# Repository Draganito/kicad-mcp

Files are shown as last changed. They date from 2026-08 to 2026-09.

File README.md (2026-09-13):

# kicad-mcp

I built this because I needed a replacement LED panel for my
**Beseler 4×5** enlarger (MILUKA Aristo D2). I had never designed a
PCB, and I did not want to learn KiCad by clicking through menus.

So you keep **KiCad** open. In **Cursor** you tell an assistant what
the board should be — in plain language. It downloads the real JLCPCB
parts, places them, assigns the nets, pours the copper, checks its own
work, and writes the files JLCPCB actually accepts.

This is not a second PCB editor and not “chat, invent a `.kicad_pcb`”.
KiCad stays the source of truth. Every change is **Ctrl+Z**. Nothing
is saved unless you ask.

**Proof it works:** the board that started it —
[contrib/aristo-d2-led-panel](contrib/aristo-d2-led-panel), 109 SK6812
LEDs, 4 layers, designed this way from the first outline to the
ordered Gerbers, manufactured by JLCPCB.

**Work in progress:**
[contrib/aristo-d2-led-panel-v2](contrib/aristo-d2-led-panel-v2) —
112× WS2812B-MINI drop-in. Layout and gerbers only; not a build guide.

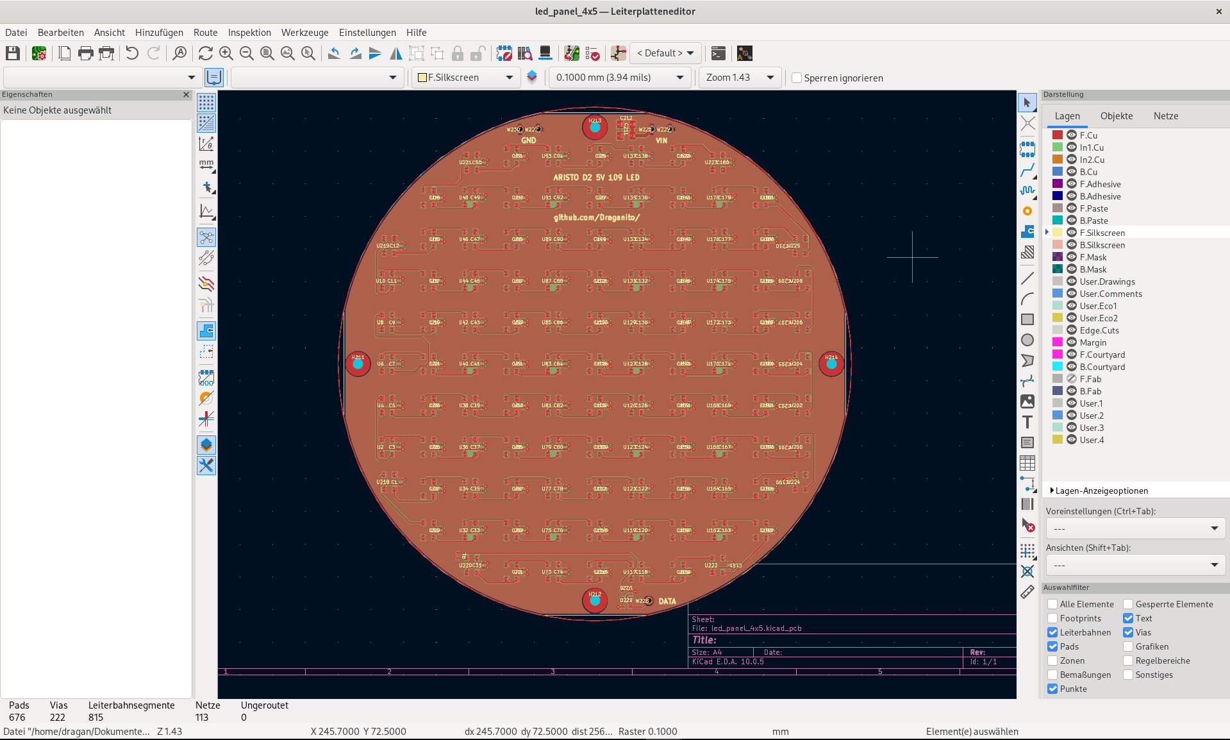
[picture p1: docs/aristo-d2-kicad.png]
MILUKA Aristo D2 replacement LED panel in KiCad


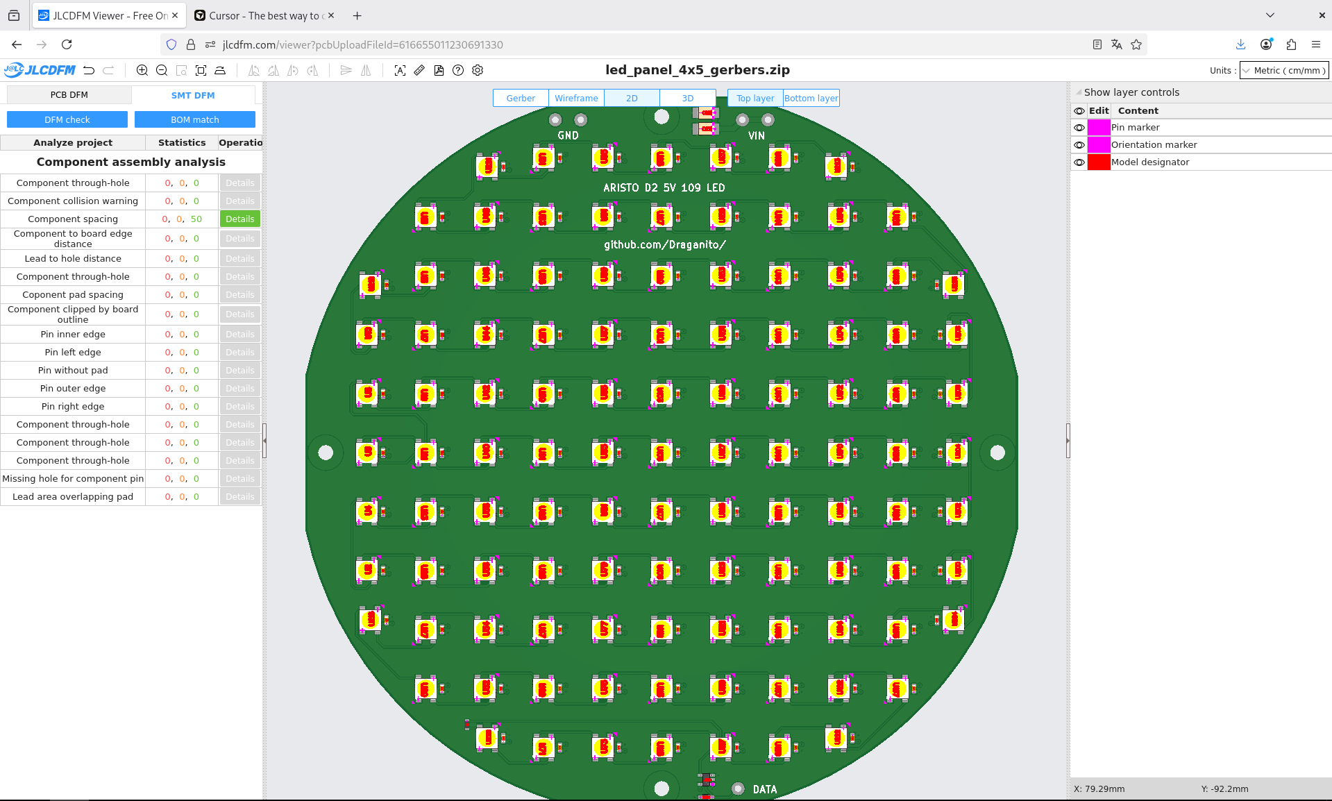
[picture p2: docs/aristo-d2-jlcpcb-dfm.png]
MILUKA Aristo D2 replacement LED panel in JLCPCB DFM


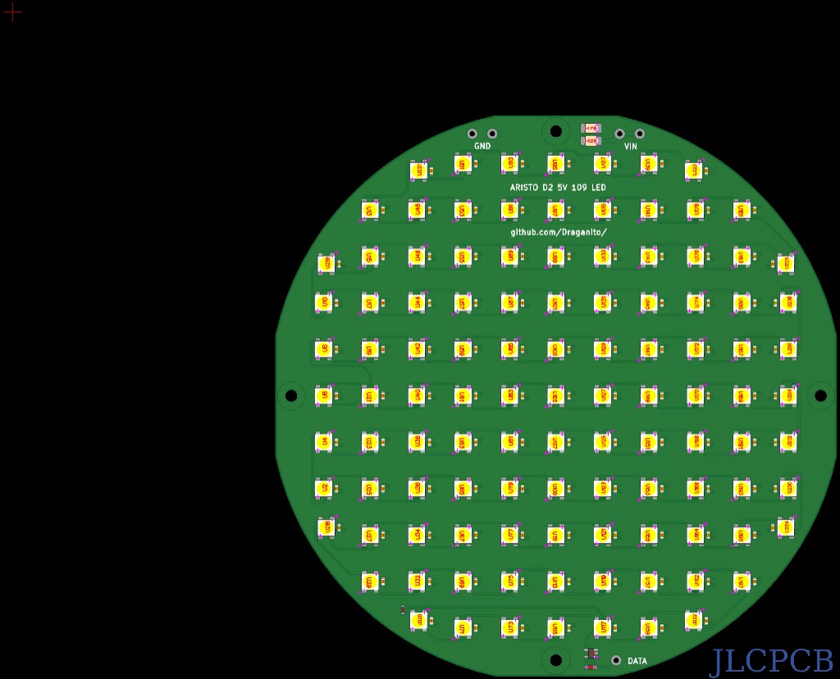
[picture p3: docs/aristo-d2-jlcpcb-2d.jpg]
MILUKA Aristo D2 replacement LED panel, JLCPCB 2D view


**Docs:** [Install on Debian](docs/INSTALL_DEBIAN.md) ·
[Manual (A–Z reference)](docs/MANUAL.md)

---

## Who this is for

Students, hobbyists, makers on **Debian/Ubuntu** who want help with
the boring bits: a LED grid, wire pads, a GND pour, Gerbers that
JLCPCB accepts — without learning a pro tool first.

You still decide the circuit. The assistant must not invent pin
functions — those come from the LCSC / EasyEDA part, and built-in
checks (`check_pins`, `check_placement`, `review_board`) force it to
account for every pin instead of hand-waving.

Skip this if you layout in Altium, only have Windows, or do not want
an assistant in the editor at all.

---

## What you need

- A PC with Debian or Ubuntu (x86-64)
- [KiCad 10](https://www.kicad.org/download/linux/) — not Debian’s
  KiCad 9
- [Cursor](https://cursor.com)
- An LCSC part number when you want a real JLCPCB footprint
  (e.g. `C14663` for an 0603 cap)

---

## Install

1. Download the latest `kicad-mcp_*.deb` from
   **[Releases](https://github.com/Draganito/kicad-mcp/releases)**.
2. Install it:

   ```bash
   sudo apt install ./kicad-mcp_*_amd64.deb
   ```

3. Start KiCad with **`kicad-10`** (comes with the package). Open the
   PCB editor. Enable **Preferences → Plugins → Enable IPC API**, then
   restart KiCad and open the PCB editor again.
4. Copy the Cursor template into the folder you will open:

   ```bash
   cp -a /usr/share/kicad-mcp/cursor-setup/.cursor \
         /usr/share/kicad-mcp/cursor-setup/.cursorignore .
   ```

5. In Cursor, toggle the `kicad-mcp` server off and on.

The autorouter (`kicad-routing-tools_*.deb`, same Releases page) is
**optional**. If you want it: install it too, then run
`kicad-routing-tools-setup` once as your user.

Full walkthrough from a clean machine (AppImage, both packages):
[docs/INSTALL_DEBIAN.md](docs/INSTALL_DEBIAN.md).

---

## First thing to ask

KiCad 10 running, a board open, Cursor on that folder:

> Call `board_summary`.

You want KiCad **10.x**, `has_open_board: true`, and
`net_ipc_persists: true`. If it says 9.x, you started the wrong KiCad
— use `kicad-10`.

Then, in plain language, for example:

> Make a 40 × 30 mm board. Download C14663. Place one cap in the
> middle. Don’t save yet.

Undo is always **Ctrl+Z** in KiCad. The assistant must not save
unless you ask.

---

## How a board usually gets built

1. **Outline** — the yellow Edge.Cuts rectangle *is* the PCB. The pink
   A4 frame is only the drawing sheet.
2. **Parts** — LCSC C-numbers (`download_lcsc_part`), then place or
   a grid (`place_matrix`). Pin names come from EasyEDA, not from
   memory.
3. **Nets** — ratsnest only (`connect_many`). Copper comes later.
4. **Check the nets** — `check_pins`: every pin must be netted or
   explicitly allowed open. No silent floating pins.
5. **Copper** — tracks, vias, 4-layer stack if you need it, GND/5V
   pours. Or named-net autoroute (not GND).
6. **Silk** — `5V` / `GND` / `DATA` next to wire pads. Not on copper.
7. **Check the board** — clearance (`check_drc`), connectivity
   (`check_board`), layout physics (`review_board`).
8. **Order** — `export_manufacturing` writes the JLCPCB zip + BOM +
   pick-and-place. Silk has no U1/C3 (JLCPCB DFM).

Coordinates are millimetres, **+x right, +y up**. Do not edit
`.kicad_pcb` by hand.

The assistant has a small tool list on purpose. The A–Z names live in
the [manual](docs/MANUAL.md).

---

## If something fails

| What you see | Usual cause |
| --- | --- |
| MCP cannot connect | PCB editor closed, or IPC API still off |
| Version 9 / nets empty | System KiCad instead of `kicad-10` |
| Writes refused | Cursor template not copied (needs `--allow-ai-write`) |
| Parts piled in the sheet corner | A bug in pad coordinates — not you; say so |
| AppImage runs, no socket | `.AppImage` started directly instead of `kicad-10` |

More: [manual](docs/MANUAL.md) → “Troubleshooting”.

---

## Build from source

Only if you are changing the Rust code. Makers can stop at the `.deb`.

```bash
cargo test --workspace
cargo build --release -p kicad-mcp
```

Debian package: `dist/make_beta_package.sh` (needs `cargo-deb`).
Point Cursor at the **built binary**, not `cargo run`. After a rebuild,
toggle the MCP server off/on.

Layout of the repo: [docs/architecture.md](docs/architecture.md).

---

## License

[AGPL-3.0-only](LICENSE) — Copyright © 2026 Dragan Bojovic.
See [NOTICE](NOTICE).

KiCad is a separate GPL-3.0 program. This repo only talks to it over
the published IPC API.

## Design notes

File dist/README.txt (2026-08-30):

kicad-mcp — Debian package
==========================

Prebuilt Linux build of kicad-mcp (AGPL-3.0) as a .deb package.
Lay out a PCB in a running KiCad PCB editor, from Cursor.
Footprints come from EasyEDA/LCSC so they match JLCPCB.
Start here: README.md (same doc folder).
Source: https://github.com/Draganito/kicad-mcp
License notices: LICENSE.txt

Install
-------
  sudo apt install ./kicad-mcp_<version>_amd64.deb

What is where
-------------
  /usr/bin/kicad-mcp                          MCP server (stdio, Linux x86-64)
  /usr/bin/kicad-10                           Wrapper: AppImage with TMPDIR=/tmp
  /usr/share/applications/kicad-10.desktop    Menu entry
  /usr/share/kicad-mcp/cursor-setup/          Cursor setup: MCP config,
                                              AI rules, .cursorignore
  /usr/share/doc/kicad-mcp/                   This file, README.md,
                                              LICENSE.txt, docs — including
                                              fresh install:
                                              docs/INSTALL_DEBIAN.md
                                              A-Z reference:
                                              docs/MANUAL.md

Requirements
------------
- Debian/Ubuntu x86-64, glibc 2.39+ (ldd --version)
- KiCad 10 AppImage with the PCB editor open (not the Debian 9 package)
- In KiCad: Preferences -> Plugins -> Enable IPC API, then restart KiCad
- Always start via kicad-10 (TMPDIR=/tmp, otherwise MCP cannot find the
  socket). Fresh install: docs/INSTALL_DEBIAN.md
- Optional: kicad-routing-tools_*.deb from the same release, then
  kicad-routing-tools-setup (as your user). MCP and plugin do not call
  each other.

Start
-----
  Cursor launches the binary itself (stdio). Copy the contents of
  /usr/share/kicad-mcp/cursor-setup/ (.cursor/ AND .cursorignore)
  into your Cursor project folder.

  Write access: mcp.json passes --allow-ai-write (preconfigured).
  Without that flag every write tool refuses.

Product
-------
- Not a second PCB editor, not an autorouter
- The board is Edge.Cuts in KiCad; never edit .kicad_pcb by hand
- LCSC parts via download_lcsc_part (EasyEDA geometry)
- Place, nets, tracks, vias, copper zones via MCP
- check_pins: every pin netted or explicitly allowed open
- export_manufacturing: Gerber zip + BOM + CPL for JLCPCB
  (silk without reference designators — avoids DFM silkscreen-to-pad)
- Every write lands on KiCad's undo stack (Ctrl+Z)

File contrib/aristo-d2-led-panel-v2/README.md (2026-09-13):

# MILUKA Aristo D2 LED panel v2 — work in progress

**Work in progress.** Do not order this board yet. There is no build
guide here.

The shipping panel (109× SK6812, BOM, order walkthrough) is
[aristo-d2-led-panel](../aristo-d2-led-panel).

This folder is the next drop-in head: Ø 157 mm, 4-layer, **112×
WorldSemi WS2812B-MINI-JT01/W** (LCSC `C42417599`). KiCad files,
gerbers, BOM and CPL are in the tree so the layout can be reviewed.
Firmware notes, photos of *this* revision, and the order walkthrough
are not ready.

| File | What |
| --- | --- |
| [led_panel_4x5.kicad_pcb](led_panel_4x5.kicad_pcb) | PCB |
| [led_panel_4x5_gerbers.zip](led_panel_4x5_gerbers.zip) | JLCPCB gerbers (includes back silk datasheet) |
| [led_panel_4x5_bom.csv](led_panel_4x5_bom.csv) | BOM |
| [led_panel_4x5_cpl.csv](led_panel_4x5_cpl.csv) | pick-and-place |

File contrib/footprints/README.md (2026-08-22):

# Shared footprints

Hand-verified `.kicad_mod` files from real boards built with kicad-mcp.
Drop the file into your project's `jlcpcb_parts.pretty/` folder and it
shows up in `list_parts`.

## C165948_USB-C_SMD-TYPE-C-31-M-12_1

USB-C 2.0 receptacle **TYPE-C-31-M-12** (HRO / Korean Hroparts Elec),
LCSC **C165948** — the part JLCPCB stocks for basic assembly.

Checked dimension by dimension against the HRO "RECOMMEND P.C.B LAYOUT
(COMPONENT SIDE)" drawing (tolerance ±0.05 mm):

- 12 signal pads: 8×0.30 mm + 4×0.60 mm wide, 1.64 mm tall, 0.50 mm
  pitch, spans 2.50 / 3.50 / 4.80 / 6.40 mm
- 4 shield mounts: 0.90 mm pads with **oblong slots** — 0.60×1.70 mm
  (top pair), 0.60×1.40 mm (bottom pair), 8.65 mm apart, 4.18 mm
  between rows
- 2 positioning pegs: Ø0.60 mm **NPTH**, 5.78 mm apart, 0.50 mm below
  the pad row

Needs kicad-mcp ≥ 0.1.0-11: older versions dropped the NPTH pegs and
collapsed the oblong slots to 0.6 mm round holes when baking pads onto
the board.

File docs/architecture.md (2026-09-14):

# Architecture

kicad-mcp is a small Rust workspace that talks to a **running KiCad PCB
editor** over the official IPC API (protobuf / NNG). Cursor launches the
binary as a **stdio MCP** server.

```text
Cursor  --stdio MCP-->  kicad-mcp  --KiCad IPC-->  pcbnew (KiCad 10)
                              |
                              +-- easyeda-kicad --> LCSC/EasyEDA HTTP
```

## Crates

- `kicad-mcp` — MCP tools, IPC session, placement, nets, copper, silk, graphics, review, outline.
- `easyeda-kicad` — fetch an LCSC C-number and emit `.kicad_mod` /
  `.kicad_sym` / `{template}.pins.json` (Y-flip EasyEDA → KiCad).
  Pin names/functions are EasyEDA SVG names, not a manufacturer PDF.

There is no in-process board model. KiCad owns the file. Writes go
through `CreateItems` / `UpdateItems` / `DeleteItems` inside a KiCad
commit (one Ctrl+Z).

## Coordinates

KiCad native millimetres, origin = board origin, +x right, +y up. The
A4 frame is the drawing sheet; the PCB is Edge.Cuts.

## Placement

`CreateItems` stores `FootprintInstance.position` but draws nested pads
at the raw coordinates in the protobuf. `place.rs` bakes board
millimetres into every pad (and silk/fab text). Dropping that bake
puts copper at the sheet corner.

## Nets (KiCad 10)

`connect_pins` splices `Pad.net` into the parent footprint and
`UpdateItems` it. `disconnect_pin` splices the same field back to
unconnected (code 0). Every pad that shares the pin number is assigned
or cleared (thermal clusters). A free-pad update is rejected. KiCad 10 persists
`Pad.net` / `Track.net`. `board_summary.net_ipc_persists` is true from
major version 10.

Start 10 with `kicad-10` (`/usr/bin/kicad-10` from the .deb, source
`scripts/kicad-10.sh`). The wrapper forces `TMPDIR=/tmp` so the NNG
socket is `/tmp/kicad/api.sock`. Starting the `.AppImage` or
`/usr/bin/kicad` (9) breaks nets or the socket.

The optional `kicad-routing-tools` .deb is a Pcbnew plugin. `autoroute_nets`
runs its CLI (`py_router/route.py`) with pinned JLCPCB floors, reloads
the open board via `RevertDocument`, and refills copper zones. It does
not press the wx Route button. `check_drc` shells out to
`kicad-cli pcb drc` (same binary as gerber export).

## Outline replace

GetItems reports Edge.Cuts as proto name `BL_Edge_Cuts` (layer id 47),
not the UI name `Edge.Cuts`. `set_board_outline` matches both, deletes,
recreates, then refills zones. An inner closed Edge.Cuts path is a
**cutout**; leftover rectangles punch holes in copper pours.

## Overlay graphics

`add_shape` creates a `BoardGraphicShape` (native rect / circle /
polygon / line / table grid, always unfilled). Default layer is
**Cmts.User** (does not plot). F/B.Silkscreen still plot. Optional `tag`
is stored as a KiCad `Group` named `kicad-mcp:<tag>` so `clear_shapes`
can delete one overlay without wiping a silk logo. The group is a
**second undo**: KiCad 10.0.6 `PCB_GROUP::GetLayerSet` is the union of
members already on the board, so CreateItems in the same commit as the
outlines returns `no overlapping layers`. `kind: table` expands to an
outer rectangle plus inner segments (shared edges are not doubled).
`stroke_mm` is the inner grid; `border_stroke_mm` the outer rect.
`cells` (top row first, as you read the finished layer) become `BoardText`
on the same layer and need a tag so the group holds grid + text. On
B.Silkscreen the matrix is mapped onto the flipped back (do not reverse
it in the caller). `kind: line` is an open segment (board millimetres,
not flipped). Plotting silk (`F.Silkscreen` / `B.Silkscreen`) is **punched**
where the stroke would sit on a same-side copper pad (JLCPCB 0.15 mm), a
hole, or a via drill (0.18 mm + half stroke) — the outline is not refused.
Front silk vs `F.Cu`, back silk vs `B.Cu`, PTH/NPTH holes and via drills on
both. Cell text is the KiCad stroke font: a letter on a hole is gapped, the
rest of the line stays BoardText. Refused only if nothing remains. User
layers are not checked. `kind: rect`
+ `reference` (e.g. `"U1"`) draws the package body (JLCPCB `L…-W…` / EIA
size at the footprint origin), then clips
the pads. `get_shapes` also lists grouped overlay texts (`kind: text`)
in reading order; untagged `add_text`
labels are omitted. `clear_shapes` deletes only managed layers (and those overlay groups,
including cell text). Edge.Cuts is never in that set — a cover overlay
must not become a board cutout. Layer parsing
matches Edge.Cuts **before** copper (`edge.cuts` contains the substring
`.cu`). `get_shapes` decodes the PolyLine and reports `polygon_points` as
outline vertices, not `PolySet.polygons.len()`.

## Packaging

`dist/make_beta_package.sh` builds `target/release/kicad-mcp` and runs
`cargo deb -p kicad-mcp`. The `.deb` ships `/usr/bin/kicad-mcp`, docs,
and `contrib/cursor-setup`. The Aristo D2 LED panel that started the
tool is `contrib/aristo-d2-led-panel`. The denser WS2812B-MINI
revision is `contrib/aristo-d2-led-panel-v2` (work in progress). Live
scratch boards under
`kicad_projekte/` and `.cursor/` stay out of git.

## Manufacturing export

`export_manufacturing` saves the open board, then shells out to
`kicad-cli pcb export gerbers|drill|pos` (KiCad's plotter — this crate
does not parse `.kicad_pcb`). Gerber silk is plotted with
`--exclude-refdes` and `--exclude-value` so JLCPCB DFM does not report
silkscreen-to-pad / silkscreen-to-hole on dense boards; designators
stay in BOM/CPL only. Overlay outlines on F/B.Silkscreen plot with
that silk; the tool warns (`warning` + `silk_overlay_count`) instead of
refusing. BOM rows are grouped from live footprints
(LCSC C-number from the EasyEDA template name). CPL is the KiCad
position CSV rewritten to JLCPCB columns:
`<stem>_gerbers.zip`, `<stem>_bom.csv`, `<stem>_cpl.csv`.

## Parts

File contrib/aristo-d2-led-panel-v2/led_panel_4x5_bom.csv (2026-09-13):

Comment | Designator | Footprint | LCSC Part #
C14663_C0603 | C1, C10, C100, C101, C102, C103, C104, C105, C106, C107, C108, C109, C11, C110, C111, C112, C12, C13, C14, C15, C16, C17, C18, C19, C2, C20, C21, C22, C23, C24, C25, C26, C27, C28, C29, C3, C30, C31, C32, C33, C34, C35, C36, C37, C38, C39, C4, C40, C41, C42, C43, C44, C45, C46, C47, C48, C49, C5, C50, C51, C52, C53, C54, C55, C56, C57, C58, C59, C6, C60, C61, C62, C63, C64, C65, C66, C67, C68, C69, C7, C70, C71, C72, C73, C74, C75, C76, C77, C78, C79, C8, C80, C81, C82, C83, C84, C85, C86, C87, C88, C89, C9, C90, C91, C92, C93, C94, C95, C96, C97, C98, C99 | C0603 | C14663
C79111_CAP-SMD_L3.5-W2.8-R-RD | C211, C212 | CAP-SMD_L3.5-W2.8-R-RD | C79111
C42417599_LED-SMD_4P-L3.5-W3.5-TL_WS2812B_WS | U1, U10, U100, U101, U102, U103, U104, U105, U106, U107, U108, U109, U11, U110, U111, U112, U12, U13, U14, U15, U16, U17, U18, U19, U2, U20, U21, U22, U23, U24, U25, U26, U27, U28, U29, U3, U30, U31, U32, U33, U34, U35, U36, U37, U38, U39, U4, U40, U41, U42, U43, U44, U45, U46, U47, U48, U49, U5, U50, U51, U52, U53, U54, U55, U56, U57, U58, U59, U6, U60, U61, U62, U63, U64, U65, U66, U67, U68, U69, U7, U70, U71, U72, U73, U74, U75, U76, U77, U78, U79, U8, U80, U81, U82, U83, U84, U85, U86, U87, U88, U89, U9, U90, U91, U92, U93, U94, U95, U96, U97, U98, U99 | LED-SMD_4P-L3.5-W3.5-TL_WS2812B_WS | C42417599
C23138_R0603 | R1 | R0603 | C23138
C502527_SOD-323_L1.8-W1.3-LS2.5-FD | D229 | SOD-323_L1.8-W1.3-LS2.5-FD | C502527
C7484_SOT-23-5_L3.0-W1.7-P0.95-LS2.8-BR | U226 | SOT-23-5_L3.0-W1.7-P0.95-LS2.8-BR | C7484

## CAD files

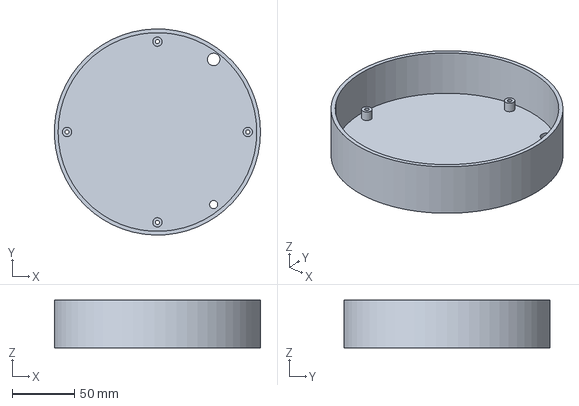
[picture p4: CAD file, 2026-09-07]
contrib/panel-holder-freecad/panel-holder.FCStd
164.9 x 164.9 x 38.2 mm

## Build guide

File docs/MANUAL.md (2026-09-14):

# kicad-mcp — Manual

A-to-Z reference. New here? Start with the [README](../README.md).
Fresh machine: [INSTALL_DEBIAN.md](INSTALL_DEBIAN.md).

---

## Contents

1. [What it is](#1-what-it-is)
2. [Install](#2-install)
3. [Prepare KiCad](#3-prepare-kicad)
4. [Cursor / MCP](#4-cursor--mcp)
5. [Coordinates and outline](#5-coordinates-and-outline)
6. [Parts](#6-parts)
7. [Nets](#7-nets)
8. [Copper](#8-copper)
9. [Tool catalogue](#9-tool-catalogue)
10. [Save and undo](#10-save-and-undo)
11. [Building the Debian package](#11-building-the-debian-package)
12. [Troubleshooting](#12-troubleshooting)
13. [Deliberate limits](#13-deliberate-limits)

---

## 1. What it is

You keep KiCad open. From Cursor an assistant lays out the board in
the editor you already see. KiCad stays the source of truth; this is
not a second layout program.

Technically: a **stdio MCP server** that drives the **PCB editor**
over the official IPC API. `autoroute_nets` can run the companion CLI
for named nets.

JLCPCB footprints come from **EasyEDA / LCSC** (`download_lcsc_part`).
Wire pads and mounting holes are generated parametrically:
`list_parts` writes the defaults (`WirePad_PTH` 2.5/1.5 mm,
`MountingHole_M3_NPTH` 3.2 mm); `make_wire_pad` / `make_mounting_hole`
write any other size (e.g. `WirePad_PTH_3.2_2`, `MountingHole_4.5_NPTH`).
Mounting-hole keepout copper has **no** soldermask opening (laminate, not a HASL ring).

License: AGPL-3.0-only. KiCad itself is a separate GPL-3.0 program and
is not shipped in this package.

## 2. Install

### Prebuilt package

From [GitHub Releases](https://github.com/Draganito/kicad-mcp/releases)
both files (MCP + optional autorouter):

```bash
sudo apt install ./kicad-mcp_<version>_amd64.deb ./kicad-routing-tools_0.20.4-2_amd64.deb
kicad-routing-tools-setup
```

Step by step: [INSTALL_DEBIAN.md](INSTALL_DEBIAN.md).
Debian/Ubuntu x86-64, glibc 2.39+. **KiCad 10** must be running
(`recommends: kicad` is only the distro package — on Debian 13 that is
9.0.2 and is not enough for nets). After the MCP `.deb`, `kicad-10`
starts the AppImage with `TMPDIR=/tmp`.

### From source

```bash
cargo test --workspace
cargo build --release -p kicad-mcp
```

Binary: `target/release/kicad-mcp`.

## 3. Prepare KiCad

kicad-mcp targets **KiCad 10**. Nets from `connect_many` /
`set_copper_zone` persist there. Do not use Debian 13's system KiCad 9.

1. Official AppImage: [kicad.org/download/linux](https://www.kicad.org/download/linux/)
   — **Lite** is enough. Some browsers save
   `kicad-10.0.5-x86_64.AppImage.tar`: `tar -xf … -C ~/Programme`.
2. `chmod +x ~/Programme/kicad-10.0.5-x86_64.AppImage`
3. **Always** start through the wrapper, not the `.AppImage` and not
   `/usr/bin/kicad`. The AppImage remaps `TMPDIR` under `~/.cache/tmp`;
   MCP looks for `ipc:///tmp/kicad/api.sock`.

```bash
kicad-10
```

`/usr/bin/kicad-10` (from the `.deb`, source `scripts/kicad-10.sh`) sets
`TMPDIR=/tmp` and launches the AppImage from `~/Programme/` (or
`KICAD_10_APPIMAGE`). Menu entry: **KiCad 10 (AppImage)**.

4. Open the PCB editor (a board must be loaded).
5. **Preferences → Plugins → Enable IPC API**, restart KiCad.
6. `board_summary` must show `10.0.x` and `net_ipc_persists: true`.
   Toggle the Cursor MCP server if 9 was running before.

Without the IPC API every tool fails (socket error).

`export_manufacturing` needs `kicad-cli` **from KiCad 10**
(`/tmp/.mount_kicad*/bin/kicad-cli`), not the system 9 binary.

## 4. Cursor / MCP

After the `.deb` install, copy the contents of
`/usr/share/kicad-mcp/cursor-setup/` into the Cursor project folder
(`.cursor/` and `.cursorignore`).

`mcp.json` launches `/usr/bin/kicad-mcp --allow-ai-write`. From a
source tree, point at `target/release/kicad-mcp` or
`target/debug/kicad-mcp` — **not** `cargo run`. After Rust changes:
rebuild, then toggle the MCP server off/on.

Without `--allow-ai-write` every write tool refuses.

`.cursorignore` hides `.kicad_pcb` / `.kicad_sch` so the model cannot
edit them by hand.

## 5. Coordinates and outline

- Units: **millimetres**, KiCad origin, **+x right, +y up**.
- The pink A4 frame is the **drawing sheet** (297 × 210 mm), not the PCB.
- The PCB is **Edge.Cuts** (`set_board_outline`).
- Rectangle: `width_mm` / `height_mm`. Origin = bottom-left. If origin
  is omitted, the rectangle is centred on the sheet, not at 0,0.
- Polygon: `points: [{x_mm, y_mm}, ...]` (max 400, closed automatically).
- Default `replace=true` deletes existing Edge.Cuts (including when
  KiCad reports the layer as `BL_Edge_Cuts`) and refills copper zones.

`clear_board` deletes footprints, tracks, vias, zones, silk text and overlay outlines — Edge.Cuts stays.

## 6. Parts

1. `download_lcsc_part` with a C-number (e.g. `C5348912`) writes EasyEDA
   geometry into `jlcpcb_parts.pretty` next to the open board and
   returns `pins: [{number, pin_name}]` (EasyEDA function).
2. `list_parts` names the templates `place_footprint` wants.
   `get_part_pins` rereads those EasyEDA names for an already downloaded
   template (`{template}.pins.json`); the LCSC C-number (`C5348912`) is
   enough when it is unique.
3. `place_footprint` / `place_parts` (max 150, one undo) /
   `place_matrix` (grid: origin = cell 0,0, +x columns, +y rows,
   pitch centre-to-centre).

Placement checks F.CrtYd overlap between footprints. `move_footprint`
relocates and/or rotates a placed part in one undo: a rigid transform
of the anchor and every baked pad, so nets, reference and padstack
geometry survive (no remove+place). The target is courtyard-checked.
Copper does **not** move — re-route tracks that reached the part.
Do not substitute a generic KiCad library footprint for an LCSC
C-number.

`get_pads` reports every pad as hard data straight from KiCad's baked
protos: reference, pin, net, absolute x/y, size, rotation, smd/pth/npth,
shape, layer, `layers` (every copper layer on the padstack — a 5V PTH
without `In1.Cu` cannot take thermals from the power pour), drill;
filter by `reference` and/or `net`. Use it to
verify placement and orientation (a mirrored or mis-rotated part shows
pads on the wrong side of the anchor) instead of guessing from
templates or renders.

`check_placement` turns that into a hard OK/fail audit: every pad is
recomputed from its `jlcpcb_parts` template at the footprint's anchor +
rotation and compared against the baked board pads. A mirrored,
mis-rotated or stale-baked part (placed by an older kicad-mcp) fails
with per-pad deltas in mm — pin, expected vs actual position, plus
size/angle/type/drill mismatches (a lost NPTH hole or a slot baked as
a round hole fails too). Thermal clusters that share a pin number
are matched by nearest position. Optional `reference` filter,
`tolerance_mm` default 0.01. Footprints without a template on disk are
listed as `skipped`, not failed. Run it after placing or moving parts;
trust it over any render.

Nested pads are not parent-transformed. `place.rs` bakes board
millimetres into every pad. Without that bake, copper piles up at the
sheet corner (0,0) while the API still claims the part is in the middle.

## 7. Nets

Pin names and functions come from **EasyEDA** (`download_lcsc_part` /
`get_part_pins`), not from datasheet memory and not from Alladin
`pad_nets`. `connect_pins` / `connect_many` set **Pad.net** (ratsnest),
not copper. Every pad that shares the pin number is assigned (thermal
clusters, e.g. ESP32 pad 41). Daisy-chain: omit `net`. The net is
spliced into the parent FootprintInstance — a free-pad UpdateItems is
rejected. On **KiCad 10** the name persists after save; `get_nets` /
`check_board` must show it. `disconnect_pin` / `disconnect_many` clear
that assignment back to unconnected (same splice, code 0). Idempotent
if the pin is already open. Does not rip copper.

After netting, run **`check_pins`** — the ERC substitute for the
schematic-less workflow. It groups every electrical pad into `REF.PIN`
pins (NPTH and unnumbered pads are skipped), lists `open_pins` without a
net (annotated with the EasyEDA `pin_name`, so a floating `1OE#` reads
differently from a floating `NC`) and `single_pad_nets` — nets that
reach exactly one pin, netted but connecting nothing. Intentionally
open pins go into `allow: ["U226.5"]`; an allow entry that matches no
open pin fails the report (typo guard). `ok` only when every pin is
netted or explicitly allowed — never silently accept a floating enable
or input.

A manufacturer PDF is allowed only after a **logic check** shows the
EasyEDA names cannot be right (example: WROOM pad 1 named `IO20` while
pin 1 is the module GND corner). Then fetch hard facts (`datasheet_url`
if EasyEDA sent one), name the contradiction, and net from that. 0603
parts whose EasyEDA names are only `1`/`2` have no polarity — GND vs
rail from the companion pad.

## 8. Copper

- `add_track` / `add_tracks` (max 150, one undo)
- `add_via` / `add_vias` (max 150)
- `stitch_via` — GND via + F.Cu stub next to a pin or every SMD pad on
  a net (`net: "GND"`)
- `set_copper_layers` — copper count 2/4/6/8 (not undoable)
- `set_copper_zone` — rectangle or polygon; net e.g. `5V` / `GND`;
  layer `F.Cu` / `In1.Cu` / `In2.Cu` / `B.Cu`; pads solid unless `thermal=true` (PTH) or `thermal_smd=true` (SMD+PTH); `remove_islands=true` drops isolated slivers; then refill
- `clear_zones` — delete copper zones (tracks stay)
- `ripup_wire` — `segment_id` from `get_routing_scene` (optional `net`)
- `autoroute_nets` — named nets via the plugin CLI, then reload and
  refill zones
- `check_drc` — `kicad-cli pcb drc` (clearance, silk, holes); saves
- `review_board` — read only: GND/power pour, adjacent layers, via
  at each cap GND (3 mm), PTH wire pads vs those pours (thermals vs
  clearance), SK6812 daisy (DOUT→DIN), 0603 cap GND next to LED pin 1
  (bulk at the connector is skipped).
  Not DRC, not 90° corners. Before “done”.

### Silk text

`add_text` / `add_texts` (max 150, one undo) places board text on
**F.Silkscreen** (default) or **B.Silkscreen**. Use it for connector
names (`5V`, `GND`, `DATA`) next to wire pads. Never F.Cu, never the
footprint Value (export already strips U1/C3). Size default 1.0 mm
(min 0.8). `clear_board` deletes these labels.

### Overlay outlines (cover / mask)

`add_shape` / `add_shapes` (max 150 items after expansion, one undo)
draws **unfilled** rectangles, circles, polygons, **lines** or a
**table** (grid of lines, optional cell text) so you can overlay a
mechanical cover on the LEDs or a datasheet next to a part.

- Default layer **Cmts.User** (check-only, **does not plot**). Turn on
  User.Comments in the KiCad layer widget or the overlay is invisible.
  `Dwgs.User` / `Eco1.User` / `Eco2.User` also do not plot.
- **F.Silkscreen** / `B.Silkscreen` **plot to gerbers**. Use `B.Silkscreen`
  when the table is a printed datasheet. `export_manufacturing` **warns**
  if silk overlays are still on the board (`warning` + `silk_overlay_count`).
- `tag` (e.g. `"4x5"`, `"table"`) stores a KiCad group named
  `kicad-mcp:<tag>`. `clear_shapes tag="4x5"` deletes that overlay without
  wiping a silk logo. `replace=true` with a tag replaces only that group;
  without a tag it still clears the layer used. The group is a second
  undo (KiCad 10 needs members on the board before CreateItems will accept
  the group). Cell text **requires** a tag so the group holds grid + text.
- Never Edge.Cuts (that is the board / a cutout), never copper, never
  filled. `"edge.cuts"` is refused as a cutout, not as copper.
- Rect: `origin_x_mm` / `origin_y_mm` (bottom-left, +y up) **or**
  `center_x_mm` / `center_y_mm`, plus `width_mm` / `height_mm`.
  **`reference`** (e.g. `"U1"`) with `kind: rect` fills centre and size from
  that footprint's **package body** (JLCPCB `L3.5-W3.5` or EIA `R0603` at
  the footprint origin — not the copper pad envelope, and not F.CrtYd,
  which often includes silk text). Omit origin/width. Plotting silk is then
  **gapped** at pads, holes, and via drills
  (0.15 mm pad / 0.18 mm hole + half stroke) so the body outline can cross pads.
- Plotting silk (`F.Silkscreen` / `B.Silkscreen`) is **not refused** when
  a stroke crosses a pad, hole, or via. The line is interrupted with JLCPCB
  clearance. Front silk vs `F.Cu`, back silk vs `B.Cu`, PTH/NPTH holes and
  via drills on both. A letter on a hole is gapped (character void); the rest
  of the line stays BoardText. Refused only if nothing remains.
  `Cmts.User` / other user layers are not checked.
- Circle: `x_mm` / `y_mm` plus `radius_mm` or `diameter_mm`.
- Polygon: `points: [{x_mm, y_mm}, …]` (closed automatically, max 400).
- Line: `a_x_mm` / `a_y_mm` + `b_x_mm` / `b_y_mm` (aliases `segment`,
  `hline`, `vline`). `hline` must be horizontal; `vline` vertical.
  Length 0.5–400 mm. Own `stroke_mm`. Several loose lines via `add_shapes`
  plus a shared `tag`.
- Table: `rows` / `cols` plus `cell_width_mm` / `cell_height_mm` (or
  overall `width_mm` / `height_mm`). Outer rectangle plus inner grid
  lines so shared edges are not double-stroked. Max 40×40 cells.
  `stroke_mm` is the inner grid (default 0.15); `border_stroke_mm` is the
  outer rect (default = inner). `cells` is `[["top-left", …], …]` as you
  **read the finished layer** (datasheet/Excel, top row first); empty string
  skips that cell. On **B.Silkscreen** that is the physical back — the tool
  maps the matrix onto the flipped board coordinates. Do **not** reverse
  rows/columns yourself. Origin/centre stay KiCad millimetres (front, +y
  up). Rows/cols are inferred from `cells` when omitted. Cell text is
  BoardText on the **same layer**, centred, `size_mm` default 1.0 (silk
  floor 0.8, user layers 0.5) and must be smaller than the cell.
  B.Silkscreen glyphs are mirrored. Loose `line` endpoints stay board mm
  (not flipped).
- `add_text` stays silk-only connector labels (`5V` / `GND` / `DATA`).
  Table cells are not that tool.
- `get_shapes` lists graphics and **grouped** overlay text (`kind: text`)
  in reading order on that layer. Untagged `add_text` labels are omitted. `polygon_points` is the outline
  **vertex count** (closing duplicate omitted), not how many polygons sit
  in the PolySet. `clear_shapes` (optional `layer` or `tag`) removes
  them, including grouped cell text.

`autoroute_nets` runs the optional KiCad Routing Tools **CLI** (not the
wx dialog). Needs `kicad-routing-tools-setup` and KiCad 10 via `kicad-10`.
`nets` is required — never `*` / every net. GND/VSS are refused (pour a
zone). USB_DN and USB_DP must be passed together (two singles plus
length-match, not `route_diff.py`). Optional `track_width_mm`,
`via_size_mm`, `via_drill_mm`, `clearance_mm` — defaults pin JLCPCB-safe
floors (0.2 mm clearance, 0.6/0.3 via) so the CLI cannot silently drop
to 0.127 mm. The step saves, writes the file, reloads, and refills
zones — **no Ctrl+Z**. Use it only when the human wants autorouting or
a full A–Z board including copper. Do not send parallel copper writes:
KiCad `BeginCommit` races.

## 9. Tool catalogue

| Tool | Kind |
| --- | --- |
| `board_summary` | Read — version, counts |
| `get_footprints` | Read — ref, position, rotation |
| `get_nets` | Read — nets and pads |
| `get_pads` | Read — baked pad truth (position, net, rotation, layers) |
| `get_shapes` | Read — overlay outlines (silk / user / tag; never Edge.Cuts) |
| `check_placement` | Read — hard OK/fail: template pads vs baked pads |
| `get_routing_scene` | Read — tracks/vias + ids; optional `net` |
| `list_parts` | Read — templates including builtins |
| `get_part_pins` | Read — EasyEDA `number` + `pin_name` (C-number ok) |
| `check_board` | Read — pads with empty net |
| `check_pins` | Read — pin coverage: open pins (with `pin_name`), `allow` list, single-pad nets |
| `review_board` | Read — physics report (pour, return, cap via, PTH, daisy, cap polarity) |
| `download_lcsc_part` | Write — EasyEDA → library + pins |
| `make_wire_pad` | Write — parametric PTH wire pad template |
| `make_mounting_hole` | Write — parametric NPTH hole template |
| `place_footprint` | Write |
| `place_parts` | Write — batch |
| `place_matrix` | Write — grid |
| `move_footprint` | Write — rigid move/rotate, nets stay, copper stays |
| `remove_footprint` | Write |
| `clear_board` | Write — parts + copper + silk text + overlay outlines, Edge.Cuts stays |
| `clear_zones` | Write — zones only |
| `set_board_outline` | Write — Edge.Cuts |
| `add_text` / `add_texts` | Write — silk label (F/B.Silkscreen) |
| `add_shape` / `add_shapes` | Write — unfilled overlay (default Cmts.User; line / table / cells; `reference` body outline; plotting silk gapped at pads) |
| `clear_shapes` | Write — overlay outlines only (layer or tag; never Edge.Cuts) |
| `connect_pins` / `connect_many` | Write — ratsnest (every same-number pad) |
| `disconnect_pin` / `disconnect_many` | Write — pin back to unconnected |
| `add_track` / `add_tracks` | Write — track |
| `add_via` / `add_vias` | Write — via |
| `stitch_via` | Write — GND via + stub |
| `set_copper_layers` | Write — copper count 2/4/6/8 |
| `set_copper_zone` | Write — pour + refill |
| `autoroute_nets` | Write — CLI autorouter, named nets |
| `ripup_wire` | Write |
| `check_drc` | Write — `kicad-cli` DRC (saves) |
| `render_board` | Write — 3D PNG via `kicad-cli pcb render` (saves) |
| `save_board` | Write — only when asked |
| `export_manufacturing` | Write — JLCPCB: `*_gerbers.zip` + `*_bom.csv` + `*_cpl.csv` (`kicad-cli`) |

`render_board` refills zones, saves, and raytraces the board to
`<stem>_render_<side>.png` via `kicad-cli pcb render` (side
top/bottom/left/right/front/back; optional `zoom`, `rotate [x,y,z]`,
`perspective`, `floor`, `width`/`height`). Copper, silkscreen, mask and
holes are real; EasyEDA footprints carry no 3D bodies, so package
orientation is verified with `get_pads`, not the render.

## 10. Save and undo

Every write lands on KiCad's undo stack (**Ctrl+Z**), except
`autoroute_nets` (file reload). Call `save_board` only when the human
asks; `autoroute_nets` and `check_drc` save internally.

`export_manufacturing` saves the open board, refills zones, and writes
three JLCPCB files into the project folder (or `out_dir`).
If overlay outlines remain on F/B.Silkscreen they **plot**; the tool
returns `warning` and `silk_overlay_count` instead of failing. Use
`Cmts.User` for a check-only overlay, or `clear_shapes` first.

| File | JLCPCB slot |
| --- | --- |
| `<name>_gerbers.zip` | PCB / Gerbers (copper, mask, silk, paste, Edge.Cuts, drill). **No** silkscreen reference designators (U1, C3, …) and no value text — on a dense grid they sit on pads/holes and fail JLCPCB silk-to-pad / silk-to-hole DFM. References live in the BOM and CPL. |
| `<name>_bom.csv` | BOM (Comment, Designator, Footprint, LCSC Part #) |
| `<name>_cpl.csv` | CPL / centroid (Designator, Mid X, Mid Y, Layer, Rotation) |

Generated wire pads and mounting holes (any size) are omitted from
BOM/CPL. Needs `kicad-cli` (the `kicad` package).

## 11. Building the Debian package

```bash
cargo install cargo-deb --locked
dist/make_beta_package.sh
```

Produces `dist/kicad-mcp_<version>_amd64.deb` (binary + `kicad-10` +
docs + Cursor setup) and `dist/kicad-routing-tools_*.deb`. Do not
commit the `.deb` files — attach them as GitHub Release assets.
MCP only: `SKIP_ROUTING_TOOLS=1 dist/make_beta_package.sh`.

## 12. Troubleshooting

| Symptom | Cause / fix |
| --- | --- |
| connect / No such file | KiCad closed, or IPC API off |
| `api.sock` missing (AppImage 10) | Started the `.AppImage` directly — use `kicad-10` (`TMPDIR=/tmp`) |
| Write refused | `--allow-ai-write` missing |
| Copper at the sheet corner | Pad-bake missing — regression in `place.rs` |
| `replaced_segments: 0` | Stale MCP binary; reload MCP after a Rust fix |
| Hole in the copper zone | Inner Edge.Cuts was a cutout; refill zones (B in KiCad) or `set_board_outline` again |
| `net_count: 1`, many unconnected / `net_ipc_persists: false` | Wrong KiCad (9) — use `kicad-10` |
| Commit already in progress | Do not send copper batches in parallel |
| `check_drc` cannot find kicad-cli | Start KiCad 10 via `kicad-10` (AppImage CLI under `/tmp/.mount_kicad*`) |

## 13. Deliberate limits

- No schematic editor. Autorouter only via `autoroute_nets`
  (named nets, companion deb).
- No editing `.kicad_pcb` through this server.
- Max 150 parts / tracks / vias / overlay outlines per undo batch.
- Polygon outline max 400 points.
- Target is **KiCad 10**. System 9 is geometry-only; nets do not persist.

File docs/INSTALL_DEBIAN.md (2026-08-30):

# Fresh install on Debian + Cursor

A clean Debian machine (x86-64, e.g. Debian 13) through to the first
question in Cursor. If the package is already installed, the short
version is in the [README](../README.md).
Reference: [MANUAL.md](MANUAL.md).

Both `.deb` files sit on the same
[Releases page](https://github.com/Draganito/kicad-mcp/releases).
They do **not** call each other:

| Package | Role |
| --- | --- |
| `kicad-mcp_*.deb` | Cursor drives KiCad (parts, nets, individual tracks) |
| `kicad-routing-tools_*.deb` | Autorouter **inside** Pcbnew (Tools → External Plugins) |

KiCad itself is **not** in either deb — official AppImage from kicad.org.

---

## 1. KiCad 10 AppImage

Debian 13 ships KiCad **9**. Nets and MCP need **10**.

1. Download **Lite** (enough) from
   [kicad.org/download/linux](https://www.kicad.org/download/linux/).
   Some browsers save `kicad-10.0.5-x86_64.AppImage.tar`:

   ```bash
   mkdir -p ~/Programme
   tar -xf kicad-10.0.5-x86_64.AppImage.tar -C ~/Programme
   chmod +x ~/Programme/kicad-10.0.5-x86_64.AppImage
   ```

2. Do **not** double-click the `.AppImage` and do **not** run
   `/usr/bin/kicad` (system 9). The AppImage remaps `TMPDIR` under
   `~/.cache/tmp`; MCP looks for `ipc:///tmp/kicad/api.sock`.

---

## 2. Both debs

Download both files from the Releases page, then:

```bash
sudo apt install ./kicad-mcp_<version>_amd64.deb ./kicad-routing-tools_0.20.4-2_amd64.deb
```

`kicad-mcp` installs:

- `/usr/bin/kicad-mcp` — MCP server
- `/usr/bin/kicad-10` — wrapper (`TMPDIR=/tmp` + AppImage)
- `/usr/share/kicad-mcp/cursor-setup/` — Cursor template
- `/usr/share/applications/kicad-10.desktop` — menu entry

`kicad-routing-tools` stores the plugin under
`/usr/share/kicad-routing-tools/`. Each user must copy it **once**:

```bash
kicad-routing-tools-setup
```

Not as root. That also unpacks numpy/scipy/shapely (CPython 3.11) into
`~/.local/share/kicad/10.0/3rdparty/python`. The AppImage has no pip —
do not run `/usr/bin/python3 -m pip` from inside KiCad
(`No module named encodings`).

---

## 3. Start KiCad and enable IPC

```bash
kicad-10
```

Or the menu entry **KiCad 10 (AppImage)**. Alternative:
`KICAD_10_APPIMAGE=/path/to.AppImage kicad-10`.

1. Open the **PCB editor** (an empty board is enough).
2. **Preferences → Plugins → Enable IPC API**.
3. Quit KiCad completely, run `kicad-10` again, open the PCB editor.

`board_summary` must later show `10.0.x` and `net_ipc_persists: true`.
If it shows 9.x: wrong KiCad — use the wrapper, not the distro package.

---

## 4. Cursor

Install [Cursor](https://cursor.com). Create a **project folder**
(or open an existing KiCad project) and copy the template in:

```bash
cd /path/to/project
cp -a /usr/share/kicad-mcp/cursor-setup/.cursor /usr/share/kicad-mcp/cursor-setup/.cursorignore .
```

Open that folder in Cursor and toggle the `kicad-mcp` MCP server off/on.
`mcp.json` launches `/usr/bin/kicad-mcp --allow-ai-write`.

Without `--allow-ai-write` every write tool refuses.

---

## 5. First check

KiCad 10 is running and the PCB editor is open. In Cursor ask:
*“call board_summary”*.

Expect: version 10.x, `has_open_board: true`, `net_ipc_persists: true`.

Typical flow:

1. MCP: outline, LCSC parts, place, **nets** (ratsnest)
2. `check_pins` — every pin netted or explicitly allowed open
3. Copper: by hand in KiCad, the plugin dialog, or MCP `autoroute_nets`
   with **named** nets (never GND, never unused GPIOs)
4. GND/5V as pours (`set_copper_zone`); autoroute 5V only if asked
5. `check_board` and after copper `check_drc`, then `export_manufacturing` if needed
6. `save_board` **only when you ask**

Undo: **Ctrl+Z** in KiCad. Do not edit `.kicad_pcb` by hand.

---

## 6. What the packages do not do

- kicad-mcp does **not** press Route. `autoroute_nets` runs the plugin
  **CLI** and reloads the file (no Ctrl+Z).
- The plugin does **not** place parts or assign nets.
- Distro `apt install kicad` stays 9 — ignore it.
- The debs do not ship the AppImage (too large, third-party license).

---

## Troubleshooting

| Symptom | Cause |
| --- | --- |
| MCP: connect / No such file | KiCad closed, PCB editor closed, or IPC API off |
| `api.sock` missing | Started the `.AppImage` directly — use `kicad-10` |
| `net_ipc_persists: false` / version 9 | System KiCad instead of AppImage 10 |
| Write refused | `--allow-ai-write` missing from `mcp.json` |
| Plugin: `No module named encodings` | pip from KiCad — run `kicad-routing-tools-setup` instead |
| Plugin missing from the menu | Setup not run as the user, or KiCad not restarted |
| Plugin pip fails | Expected: AppImage has no pip. Setup is enough |

More: [MANUAL.md](MANUAL.md) “Troubleshooting”.

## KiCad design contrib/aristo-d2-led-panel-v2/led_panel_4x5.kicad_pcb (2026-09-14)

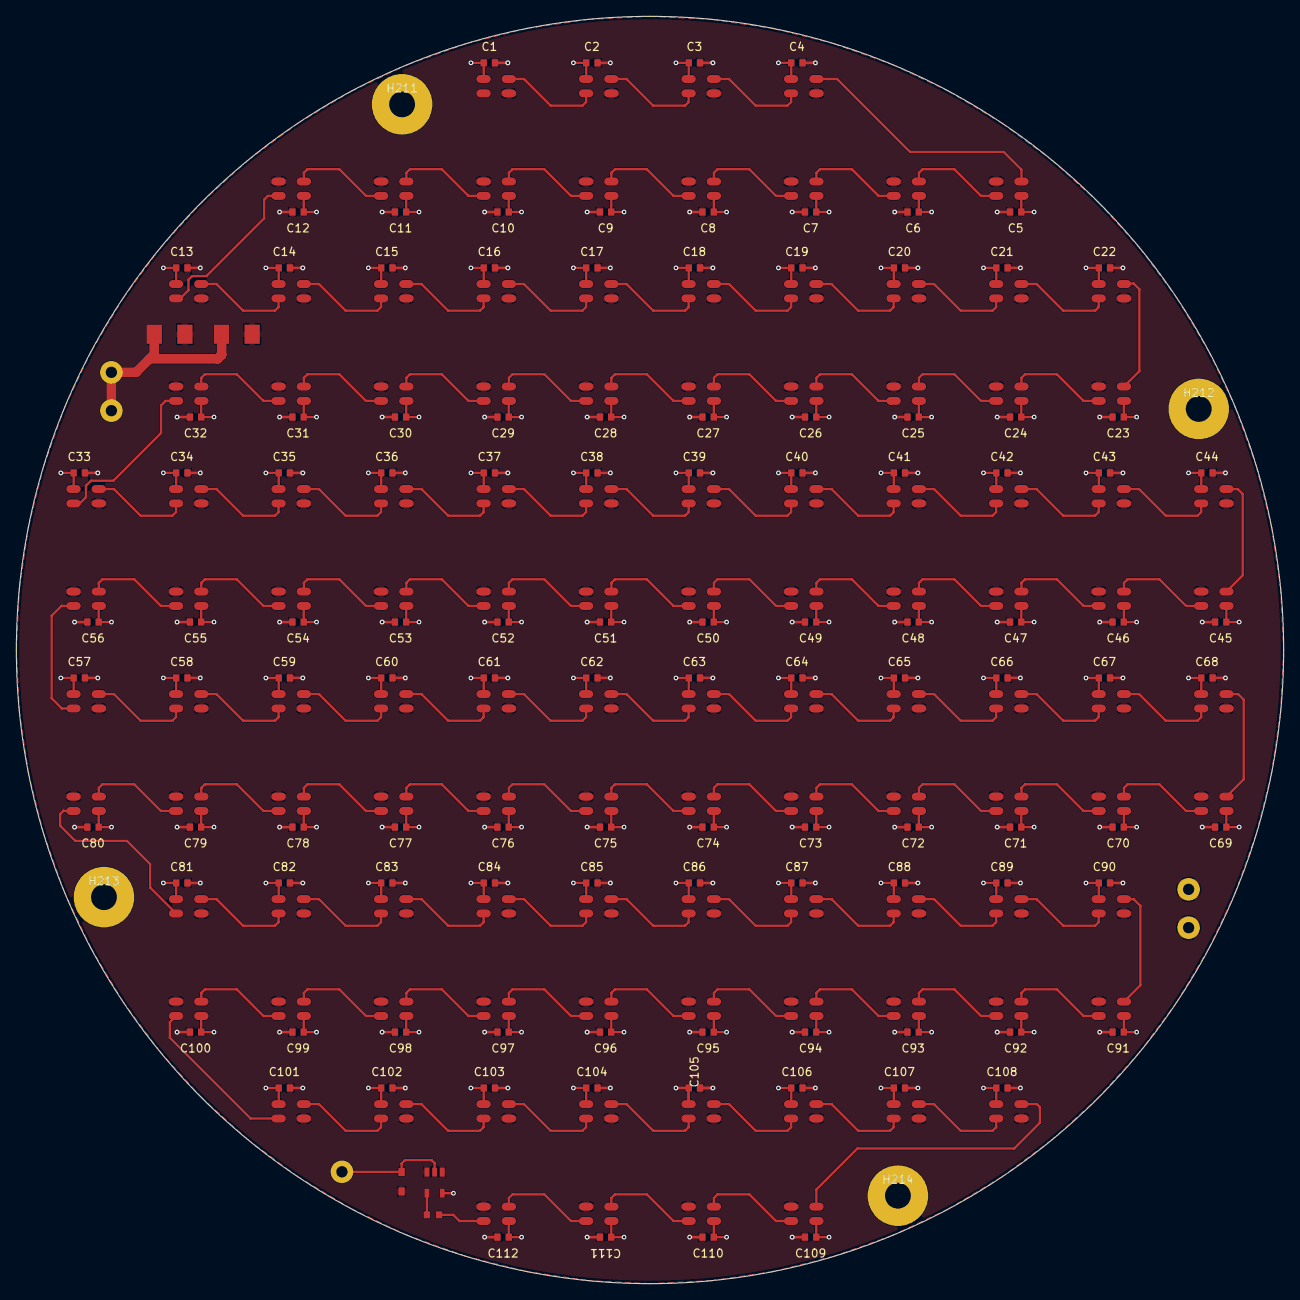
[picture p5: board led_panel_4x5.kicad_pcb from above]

Board: 4 copper layers, 157.0 x 157.0 mm, 238 parts (0 on the bottom side), 116 nets.

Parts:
C1, C2, C3, C4, C5, C6, C7, C8, C9, C10, C11, C12, C13, C14, C15, C16, C17, C18, C19, C20, C21, C22, C23, C24, C25, C26, C27, C28, C29, C30, C31, C32, C33, C34, C35, C36, C37, C38, C39, C40, C41, C42, C43, C44, C45, C46, C47, C48, C49, C50, C51, C52, C53, C54, C55, C56, C57, C58, C59, C60, C61, C62, C63, C64, C65, C66, C67, C68, C69, C70, C71, C72, C73, C74, C75, C76, C77, C78, C79, C80, C81, C82, C83, C84, C85, C86, C87, C88, C89, C90, C91, C92, C93, C94, C95, C96, C97, C98, C99, C100, C101, C102, C103, C104, C105, C106, C107, C108, C109, C110, C111, C112: C14663_C0603
C211, C212: C79111_CAP-SMD_L3.5-W2.8-R-RD
D229: C502527_SOD-323_L1.8-W1.3-LS2.5-FD
H211, H212, H213, H214: MountingHole_M3_NPTH
R1: C23138_R0603
U1, U2, U3, U4, U5, U6, U7, U8, U9, U10, U11, U12, U13, U14, U15, U16, U17, U18, U19, U20, U21, U22, U23, U24, U25, U26, U27, U28, U29, U30, U31, U32, U33, U34, U35, U36, U37, U38, U39, U40, U41, U42, U43, U44, U45, U46, U47, U48, U49, U50, U51, U52, U53, U54, U55, U56, U57, U58, U59, U60, U61, U62, U63, U64, U65, U66, U67, U68, U69, U70, U71, U72, U73, U74, U75, U76, U77, U78, U79, U80, U81, U82, U83, U84, U85, U86, U87, U88, U89, U90, U91, U92, U93, U94, U95, U96, U97, U98, U99, U100, U101, U102, U103, U104, U105, U106, U107, U108, U109, U110, U111, U112: C42417599_LED-SMD_4P-L3.5-W3.5-TL_WS2812B_WS
U226: C7484_SOT-23-5_L3.0-W1.7-P0.95-LS2.8-BR
W226, W227, W228, W229, W230: WirePad_PTH_2.8_1.4

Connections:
5V: C1.1, C2.1, C3.1, C4.1, C5.1, C6.1, C7.1, C8.1, C9.1, C10.1, C11.1, C12.1, C13.1, C14.1, C15.1, C16.1, C17.1, C18.1, C19.1, C20.1, C21.1, C22.1, C23.1, C24.1, C25.1, C26.1, C27.1, C28.1, C29.1, C30.1, C31.1, C32.1, C33.1, C34.1, C35.1, C36.1, C37.1, C38.1, C39.1, C40.1, C41.1, C42.1, C43.1, C44.1, C45.1, C46.1, C47.1, C48.1, C49.1, C50.1, C51.1, C52.1, C53.1, C54.1, C55.1, C56.1, C57.1, C58.1, C59.1, C60.1, C61.1, C62.1, C63.1, C64.1, C65.1, C66.1, C67.1, C68.1, C69.1, C70.1, C71.1, C72.1, C73.1, C74.1, C75.1, C76.1, C77.1, C78.1, C79.1, C80.1, C81.1, C82.1, C83.1, C84.1, C85.1, C86.1, C87.1, C88.1, C89.1, C90.1, C91.1, C92.1, C93.1, C94.1, C95.1, C96.1, C97.1, C98.1, C99.1, C100.1, C101.1, C102.1, C103.1, C104.1, C105.1, C106.1, C107.1, C108.1, C109.1, C110.1, C111.1, C112.1, C211.1, C212.1, U1.1, U2.1, U3.1, U4.1, U5.1, U6.1, U7.1, U8.1, U9.1, U10.1, U11.1, U12.1, U13.1, U14.1, U15.1, U16.1, U17.1, U18.1, U19.1, U20.1, U21.1, U22.1, U23.1, U24.1, U25.1, U26.1, U27.1, U28.1, U29.1, U30.1, U31.1, U32.1, U33.1, U34.1, U35.1, U36.1, U37.1, U38.1, U39.1, U40.1, U41.1, U42.1, U43.1, U44.1, U45.1, U46.1, U47.1, U48.1, U49.1, U50.1, U51.1, U52.1, U53.1, U54.1, U55.1, U56.1, U57.1, U58.1, U59.1, U60.1, U61.1, U62.1, U63.1, U64.1, U65.1, U66.1, U67.1, U68.1, U69.1, U70.1, U71.1, U72.1, U73.1, U74.1, U75.1, U76.1, U77.1, U78.1, U79.1, U80.1, U81.1, U82.1, U83.1, U84.1, U85.1, U86.1, U87.1, U88.1, U89.1, U90.1, U91.1, U92.1, U93.1, U94.1, U95.1, U96.1, U97.1, U98.1, U99.1, U100.1, U101.1, U102.1, U103.1, U104.1, U105.1, U106.1, U107.1, U108.1, U109.1, U110.1, U111.1, U112.1, U226.5, W226.1, W229.1
DATA: R1.2, U112.4
DATA_1: U1.4, U2.2
DATA_2: U2.4, U3.2
DATA_3: U3.4, U4.2
DATA_4: U4.4, U5.2
DATA_5: U5.4, U6.2
DATA_6: U6.4, U7.2
DATA_7: U7.4, U8.2
DATA_8: U8.4, U9.2
DATA_9: U9.4, U10.2
DATA_10: U10.4, U11.2
DATA_11: U11.4, U12.2
DATA_12: U12.4, U13.2
DATA_13: U13.4, U14.2
DATA_14: U14.4, U15.2
DATA_15: U15.4, U16.2
DATA_16: U16.4, U17.2
DATA_17: U17.4, U18.2
DATA_18: U18.4, U19.2
DATA_19: U19.4, U20.2
DATA_20: U20.4, U21.2
DATA_21: U21.4, U22.2
DATA_22: U22.4, U23.2
DATA_23: U23.4, U24.2
DATA_24: U24.4, U25.2
DATA_25: U25.4, U26.2
DATA_26: U26.4, U27.2
DATA_27: U27.4, U28.2
DATA_28: U28.4, U29.2
DATA_29: U29.4, U30.2
DATA_30: U30.4, U31.2
DATA_31: U31.4, U32.2
DATA_32: U32.4, U33.2
DATA_33: U33.4, U34.2
DATA_34: U34.4, U35.2
DATA_35: U35.4, U36.2
DATA_36: U36.4, U37.2
DATA_37: U37.4, U38.2
DATA_38: U38.4, U39.2
DATA_39: U39.4, U40.2
DATA_40: U40.4, U41.2
DATA_41: U41.4, U42.2
DATA_42: U42.4, U43.2
DATA_43: U43.4, U44.2
DATA_44: U44.4, U45.2
DATA_45: U45.4, U46.2
DATA_46: U46.4, U47.2
DATA_47: U47.4, U48.2
DATA_48: U48.4, U49.2
DATA_49: U49.4, U50.2
DATA_50: U50.4, U51.2
DATA_51: U51.4, U52.2
DATA_52: U52.4, U53.2
DATA_53: U53.4, U54.2
DATA_54: U54.4, U55.2
DATA_55: U55.4, U56.2
DATA_56: U56.4, U57.2
DATA_57: U57.4, U58.2
DATA_58: U58.4, U59.2
DATA_59: U59.4, U60.2
DATA_60: U60.4, U61.2
DATA_61: U61.4, U62.2
DATA_62: U62.4, U63.2
DATA_63: U63.4, U64.2
DATA_64: U64.4, U65.2
DATA_65: U65.4, U66.2
DATA_66: U66.4, U67.2
DATA_67: U67.4, U68.2
DATA_68: U68.4, U69.2
DATA_69: U69.4, U70.2
DATA_70: U70.4, U71.2
DATA_71: U71.4, U72.2
DATA_72: U72.4, U73.2
DATA_73: U73.4, U74.2
DATA_74: U74.4, U75.2
DATA_75: U75.4, U76.2
DATA_76: U76.4, U77.2
DATA_77: U77.4, U78.2
DATA_78: U78.4, U79.2
DATA_79: U79.4, U80.2
DATA_80: U80.4, U81.2
DATA_81: U81.4, U82.2
DATA_82: U82.4, U83.2
DATA_83: U83.4, U84.2
DATA_84: U84.4, U85.2
DATA_85: U85.4, U86.2
DATA_86: U86.4, U87.2
DATA_87: U87.4, U88.2
DATA_88: U88.4, U89.2
DATA_89: U89.4, U90.2
DATA_90: U90.4, U91.2
DATA_91: U91.4, U92.2
DATA_92: U92.4, U93.2
DATA_93: U93.4, U94.2
DATA_94: U94.4, U95.2
DATA_95: U95.4, U96.2
DATA_96: U96.4, U97.2
DATA_97: U97.4, U98.2
DATA_98: U98.4, U99.2
DATA_99: U99.4, U100.2
DATA_100: U100.4, U101.2
DATA_101: U101.4, U102.2
DATA_102: U102.4, U103.2
DATA_103: U103.4, U104.2
DATA_104: U104.4, U105.2
DATA_105: U105.4, U106.2
DATA_106: U106.4, U107.2
DATA_107: U107.4, U108.2
DATA_108: U108.4, U109.2
DATA_109: U109.4, U110.2
DATA_110: U110.4, U111.2
DATA_111: U111.4, U112.2
DATA_IN: D229.2, U226.2, W228.1
GND: C1.2, C2.2, C3.2, C4.2, C5.2, C6.2, C7.2, C8.2, C9.2, C10.2, C11.2, C12.2, C13.2, C14.2, C15.2, C16.2, C17.2, C18.2, C19.2, C20.2, C21.2, C22.2, C23.2, C24.2, C25.2, C26.2, C27.2, C28.2, C29.2, C30.2, C31.2, C32.2, C33.2, C34.2, C35.2, C36.2, C37.2, C38.2, C39.2, C40.2, C41.2, C42.2, C43.2, C44.2, C45.2, C46.2, C47.2, C48.2, C49.2, C50.2, C51.2, C52.2, C53.2, C54.2, C55.2, C56.2, C57.2, C58.2, C59.2, C60.2, C61.2, C62.2, C63.2, C64.2, C65.2, C66.2, C67.2, C68.2, C69.2, C70.2, C71.2, C72.2, C73.2, C74.2, C75.2, C76.2, C77.2, C78.2, C79.2, C80.2, C81.2, C82.2, C83.2, C84.2, C85.2, C86.2, C87.2, C88.2, C89.2, C90.2, C91.2, C92.2, C93.2, C94.2, C95.2, C96.2, C97.2, C98.2, C99.2, C100.2, C101.2, C102.2, C103.2, C104.2, C105.2, C106.2, C107.2, C108.2, C109.2, C110.2, C111.2, C112.2, C211.2, C212.2, D229.1, U1.3, U2.3, U3.3, U4.3, U5.3, U6.3, U7.3, U8.3, U9.3, U10.3, U11.3, U12.3, U13.3, U14.3, U15.3, U16.3, U17.3, U18.3, U19.3, U20.3, U21.3, U22.3, U23.3, U24.3, U25.3, U26.3, U27.3, U28.3, U29.3, U30.3, U31.3, U32.3, U33.3, U34.3, U35.3, U36.3, U37.3, U38.3, U39.3, U40.3, U41.3, U42.3, U43.3, U44.3, U45.3, U46.3, U47.3, U48.3, U49.3, U50.3, U51.3, U52.3, U53.3, U54.3, U55.3, U56.3, U57.3, U58.3, U59.3, U60.3, U61.3, U62.3, U63.3, U64.3, U65.3, U66.3, U67.3, U68.3, U69.3, U70.3, U71.3, U72.3, U73.3, U74.3, U75.3, U76.3, U77.3, U78.3, U79.3, U80.3, U81.3, U82.3, U83.3, U84.3, U85.3, U86.3, U87.3, U88.3, U89.3, U90.3, U91.3, U92.3, U93.3, U94.3, U95.3, U96.3, U97.3, U98.3, U99.3, U100.3, U101.3, U102.3, U103.3, U104.3, U105.3, U106.3, U107.3, U108.3, U109.3, U110.3, U111.3, U112.3, U226.1, U226.3, W227.1, W230.1
Net_R1_2: R1.1, U226.4

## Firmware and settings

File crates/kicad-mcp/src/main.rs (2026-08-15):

use clap::Parser;
use rmcp::ServiceExt;
use tracing_subscriber::EnvFilter;

use kicad_mcp::mcp::KicadMcp;

#[derive(Parser, Debug)]
#[command(
    name = "kicad-mcp",
    about = "Drive a running KiCad PCB editor from Cursor over MCP"
)]
struct Args {
    /// Enable download/place/remove/outline/nets/copper/ripup/save/export. Without this, every write tool refuses.
    #[arg(long)]
    allow_ai_write: bool,
}

#[tokio::main]
async fn main() -> anyhow::Result<()> {
    // MCP speaks on stdout — log to stderr only.
    tracing_subscriber::fmt()
        .with_env_filter(EnvFilter::from_default_env().add_directive("kicad_mcp=info".parse()?))
        .with_writer(std::io::stderr)
        .with_ansi(false)
        .init();

    let args = Args::parse();
    eprintln!(
        "kicad-mcp: stdio MCP, write tools {}",
        if args.allow_ai_write {
            "ENABLED"
        } else {
            "disabled — pass --allow-ai-write"
        }
    );
    eprintln!("kicad-mcp: KiCad must be running with Preferences → Plugins → Enable IPC API");

    let server = KicadMcp::new(args.allow_ai_write);
    let running = server.serve(rmcp::transport::stdio()).await?;
    running.waiting().await?;
    Ok(())
}

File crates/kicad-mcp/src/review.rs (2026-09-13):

//! Short layout-physics review. Reads the open board; does not place copper.
//!
//! Checks return path (ground pour), power pour, plane adjacency, a via
//! next to each decoupling-cap GND pad, SK6812 daisy (DOUT→DIN), and
//! whether a 0603 GND pad sits next to the companion LED pin 1. Does
//! **not** nag about 90° corners, silk overlap, or DRC clearance — those
//! are myths or `check_drc`.

use serde::Serialize;

use crate::copper::{self, ZoneConnectStyle, ZoneSnap};
use crate::kicad::Kicad;
use crate::pads::PadRow;

const CAP_VIA_MM: f64 = 3.0;
const CAP_VIA_WARN_MISSING: usize = 1;
/// Max centre distance from a decoupling cap to its companion LED pin 1.
/// Between a 12.7 mm LED pitch and the bulk-cap cluster at the connector.
const CAP_COMPANION_MM: f64 = 8.0;
/// Half the long pad side. 0603 is ~0.45 mm; 0805 still fits. Bulk polymer
/// (C79111 ~1.2 mm) is above this so C211/C212 at the connector are skipped
/// even when they sit inside `CAP_COMPANION_MM` of an outer LED.
const CAP_DECOUPLE_PAD_RADIUS_MM: f64 = 0.75;

#[derive(Debug, Clone, Copy, PartialEq, Eq, Serialize)]
#[serde(rename_all = "lowercase")]
pub enum Severity {
    Ok,
    Warn,
    Fail,
}

#[derive(Debug, Clone, Serialize)]
pub struct Finding {
    pub severity: Severity,
    pub id: String,
    pub detail: String,
}

#[derive(Debug, Clone, Serialize)]
pub struct ReviewReport {
    pub ok: bool,
    pub verdict: String,
    pub summary: String,
    pub findings: Vec<Finding>,
    /// Things this tool will not mention so an agent does not invent them.
    pub not_checked: Vec<String>,
}

#[derive(Debug, Clone)]
pub struct ReviewInput {
    pub copper_layers: u32,
    pub pads: Vec<PadFact>,
    pub vias: Vec<ViaFact>,
    pub zones: Vec<ZoneFact>,
}

#[derive(Debug, Clone)]
pub struct PadFact {
    pub reference: String,
    pub pin: String,
    pub net: String,
    pub x_mm: f64,
    pub y_mm: f64,
    pub kind: String,
    pub layer_ids: Vec<i32>,
    pub radius_mm: f64,
}

#[derive(Debug, Clone)]
pub struct ViaFact {
    pub net: String,
    pub x_mm: f64,
    pub y_mm: f64,
}

#[derive(Debug, Clone)]
pub struct ZoneFact {
    pub net: String,
    pub layer_ids: Vec<i32>,
    pub connection: ZoneConnectStyle,
    pub fills: Vec<copper::ZoneFill>,
}

#[derive(Debug, Clone, Copy, PartialEq, Eq)]
enum NetKind {
    Empty,
    Ground,
    Rail,
    Signal,
}

pub fn not_checked() -> Vec<String> {
    vec![
        "90° track corners (not a problem at digital / LED speeds)".into(),
        "silk overlap on EasyEDA artwork (cosmetic; export already drops U1/C3)".into(),
        "DRC clearance / holes — use check_drc".into(),
        "empty pad nets — use check_board".into(),
    ]
}

pub fn review(input: &ReviewInput) -> ReviewReport {
    let mut findings = Vec::new();
    findings.push(stack_finding(input.copper_layers));
    findings.extend(gnd_pour_finding(input));
    findings.extend(rail_pour_finding(input));
    findings.extend(adjacent_planes_finding(input));
    findings.extend(cap_via_finding(input));
    findings.extend(pth_pour_finding(input));
    findings.extend(daisy_finding(input));
    findings.extend(cap_polarity_finding(input));
    findings.extend(signal_pour_finding(input));
    findings.extend(split_gnd_finding(input));

    let fails = findings
        .iter()
        .filter(|f| f.severity == Severity::Fail)
        .count();
    let warns = findings
        .iter()
        .filter(|f| f.severity == Severity::Warn)
        .count();
    let ok = fails == 0;
    let verdict = if fails > 0 {
        "needs work"
    } else if warns > 0 {
        "ok with warnings"
    } else {
        "ok"
    };
    ReviewReport {
        ok,
        verdict: verdict.into(),
        summary: summary_line(input, &findings),
        findings,
        not_checked: not_checked(),
    }
}

pub async fn review_open_board(k: &Kicad) -> Result<ReviewReport, String> {
    let summary = k.summary().await?;
    let pads = crate::pads::board_pads(k, None, None).await?;
    let vias = k.vias().await?;
    let zones = k.copper_zones().await?;
    Ok(review(&ReviewInput {
        copper_layers: summary.copper_layer_count.unwrap_or(2),
        pads: pads.into_iter().map(pad_fact).collect(),
        vias: vias
            .into_iter()
            .filter_map(|v| {
                Some(ViaFact {
                    net: v.net.unwrap_or_default(),
                    x_mm: v.x_mm?,
                    y_mm: v.y_mm?,
                })
            })
            .collect(),
        zones: zones.into_iter().map(zone_fact).collect(),
    }))
}

fn pad_fact(p: PadRow) -> PadFact {
    let layer_ids: Vec<i32> = p
        .layers
        .iter()
        .filter_map(|n| copper::parse_copper_layer(Some(n)).ok())
        .collect();
    PadFact {
        reference: p.reference,
        pin: p.pin,
        net: p.net,
        x_mm: p.x_mm,
        y_mm: p.y_mm,
        kind: p.kind,
        layer_ids,
        radius_mm: (p.width_mm.max(p.height_mm) / 2.0).max(0.2),
    }
}

fn zone_fact(z: ZoneSnap) -> ZoneFact {
    ZoneFact {
        net: z.net,
        layer_ids: z.layer_ids,
        connection: z.connection,
        fills: z.fills,
    }
}

fn net_kind(name: &str) -> NetKind {
    let n = name.trim();
    if n.is_empty() || n.eq_ignore_ascii_case("unconnected") {
        return NetKind::Empty;
    }
    let u = n.to_ascii_uppercase().replace([' ', '-'], "");
    let u = u.trim_start_matches('+');
    if u == "0V" || u == "VSS" || u == "AGND" || u == "DGND" || u == "PGND" || u.starts_with("GND")
    {
        return NetKind::Ground;
    }
    if matches!(
        u,
        "5V" | "VCC" | "VDD" | "VBAT" | "VBUS" | "VIN" | "3V3" | "3.3V" | "1V8" | "1.8V"
    ) || u.starts_with("VCC")
        || u.starts_with("VDD")
    {
        return NetKind::Rail;
    }
    NetKind::Signal
}

fn is_cap(reference: &str) -> bool {
    let mut chars = reference.chars();
    matches!(chars.next(), Some('C') | Some('c'))
        && chars.next().is_some_and(|c| c.is_ascii_digit())
}

fn stack_finding(layers: u32) -> Finding {
    if layers <= 2 {
        Finding {
            severity: Severity::Warn,
            id: "stack".into(),
            detail: "2-layer stack: return current lives on the other copper. A split or slot in GND forces a long loop.".into(),
        }
    } else {
        Finding {
            severity: Severity::Ok,
            id: "stack".into(),
            detail: format!(
                "{layers}-layer stack: inner planes can carry return next to a power pour."
            ),
        }
    }
}
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

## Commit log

2026-08-15 Initial public tree: KiCad IPC MCP server, docs, and Debian package.
    Ship a stdio MCP that drives pcbnew, EasyEDA/LCSC footprints, and
    cargo-deb packaging so a GitHub Release can attach one .deb.
2026-08-15 Ship JLCPCB export and target KiCad 10 so nets persist over IPC.
    connect_many and zone nets stay on 10; Debian 9.0.2 is no longer the
    working path. export_manufacturing writes gerbers.zip, BOM, and CPL.
    [main.rs]
2026-08-15 Add stitch_via and keep GND vias on both copper layers.
    New boards can drop GND via+stub next to a pin (or a whole net) without Alladin coordinates; vias use real net codes and F.Cu+B.Cu rings so a 5V pour cannot swallow them.
2026-08-15 Pour 5V/GND with thermal relief and tighten stitch clearance for JLCPCB.
    SMD 5V pads and the GND wire pad need spokes for HASL/hand-solder; vias stay solid. Wider via-to-pad clearance and a 60s IPC timeout keep the slim panel rebuild reliable.
2026-08-15 Keep the public tree generic: no test-board names or rebuild scripts.
    kicad-mcp is a general KiCad IPC tool. Drop Darkroom/slim-panel paths from docs, MCP copy, and git; local rebuild helpers stay ignored.
2026-08-16 Ship a Debian+Cursor install path with the autorouter companion package.
    Users can download both debs from the same release, start KiCad 10 via
    kicad-10, and follow one guide without building from source.
2026-08-16 Add autoroute_nets so the MCP can run the Routing Tools CLI.
    Named nets only; GND is refused. The plugin writes the board file and
    KiCad reloads it, which is what makes A-to-Z copper possible.
2026-08-16 Close the layout gaps: all same-number pads, DRC, and pinned autoroute floors.
    Thermal clusters like U1.41 now get the net; autoroute refills zones and
    stays at 0.2 mm / 0.6-0.3 vias; check_drc runs kicad-cli after copper.
2026-08-16 Expose EasyEDA pin names on download so nets follow the part, not a datasheet.
    get_part_pins and pins.json make the SVG functions the default; a manufacturer PDF is only for a logic check that EasyEDA cannot be right.
2026-08-16 Add disconnect_pin so a mis-wired pad can go back to unconnected.
    EasyEDA names are sometimes wrong (AHCT125 7/8); connect_many had no inverse besides Ctrl+Z of the whole batch.
2026-08-20 Generate wire pads and mounting holes parametrically instead of hardcoding two sizes.
    make_wire_pad and make_mounting_hole write any pad/drill or NPTH size into
    jlcpcb_parts.pretty (JLCPCB drill limits, 0.25 mm annular ring enforced).
    WirePad_PTH and MountingHole_M3_NPTH remain as the default parameter sets.
2026-08-21 Stop mirroring EasyEDA footprints — .kicad_mod is y-down like EasyEDA.
    The emitter negated pad y (and rotation) assuming KiCad footprint files
    are y-up. They are not, so every converted footprint was vertically
    mirrored: the pad pattern still looked plausible, but the physical chip
    pins landed on the wrong pads (USBLC6 swapped VBUS/GND, SOT-223 swapped
    VIN/GND). Geometry now passes through unchanged; a chirality test with
    real USBLC6 fixture data guards the sense.
2026-08-21 Bake pads counterclockwise so copper matches the CPL rotation.
    world_xy used the textbook rotation matrix, which is clockwise in
    KiCad's y-down frame, while the orientation field (and the CPL export
    JLCPCB assembles from) is counterclockwise-positive. Every ±90° part
    had its body — and would have had its solder joint — 180° off the
    copper. A rotation-sense test guards the convention.
2026-08-21 Add get_pads, move_footprint and render_board tools.
    get_pads decodes the baked FootprintInstance protos over IPC — pad
    truth (position, net, rotation, kind) for verifying placement instead
    of guessing. move_footprint applies a rigid transform to the anchor and
    every baked pad via the same splice path as connect_pins, so nets and
    padstack geometry survive; the target is courtyard-checked and copper
    stays. render_board raytraces the saved board to a PNG through
    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
2026-08-22 Add check_placement to catch mirrored or stale-baked footprints.
    Compares template pads at the footprint anchor against KiCad's baked pads so orientation bugs fail with millimetre deltas instead of a 3D render.
2026-08-22 Keep NPTH pegs and oblong drill slots when baking pads.
    The template parser only knew the builtin `npth` token, so KiCad's `np_thru_hole` fell through to SMD (USB-C positioning pegs lost their holes) and oval drills collapsed to round — shield slots came out as 0.6 mm circles in the Excellon file. check_placement now audits drills too, so a stale bake fails hard.
2026-08-22 Share the hand-verified C165948 USB-C footprint in contrib.
    Checked against the HRO recommended PCB layout drawing; others can drop it into jlcpcb_parts.pretty instead of redoing the datasheet work.
2026-08-22 Add 4-layer pours, PTH thermals, and inner-layer Gerbers.
    Power planes need In1/In2 and a stack change; JLCPCB zips were dropping those layers, and wire pads need thick thermals without lifting SMD or vias off the pour.
2026-08-28 Let zones pour SMD thermals and drop isolated islands.
    LED GND pads on an F.Cu pour need 0.4 mm spokes and sliver removal; NPTH holes also keep a screw-head keepout so the pour does not sit under the fastener.
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2026-08-28 Add a short layout-physics review that reads instead of routing.
    [review.rs]
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2026-08-29 Publish the Aristo D2 LED panel and say why this tool exists.
    The Besseler 4×5 replacement board is what forced kicad-mcp into being;
    put the KiCad project and JLCPCB files in contrib and show them on the
    landing page.
    [led_panel_4x5.kicad_pcb, led_panel_4x5.kicad_sch, led_panel_4x5_bom.csv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]
2026-08-29 Show pad copper layers and review PTH thermals against pours.
    get_pads hid every layer after F.Cu, so a 5V wire pad missing In1 looked fine. Bake PTH onto the inner stack, list those layers, and let review_board sample the fill for thermals vs clearance.
    [review.rs]
2026-08-29 Let review_board walk the SK6812 daisy and cap polarity, filter routing by net, and resolve pins from a C-number.
    get_nets is the wrong shape for those checks, and agents should not need the full pretty name or every track on the board.
    [review.rs]
2026-08-29 Skip bulk polymer caps in cap_polarity so C211/C212 at the connector are not flagged.
    They sit inside 8 mm of an outer LED; only 0603-sized pads are companions.
    [review.rs]
2026-08-29 Publish the production Aristo D2 board with the power pads shifted 0.75 mm.
    JLCPCB DFM flagged THT-to-SMD clearance at the 5V/GND wire pads; the new Gerbers clear that without moving the LEDs.
    [led_panel_4x5.kicad_pcb]
2026-08-29 Show the production board from the native KiCad view and a clean JLCPCB DFM check.
    Keep the screenshots at full desktop resolution instead of the downscaled chat copies.
2026-08-30 Add check_pins so every electrical pin must be netted or explicitly allowed open.
    This is the ERC substitute for the schematic-less workflow: floating pins and single-pad nets fail unless justified, with EasyEDA pin names in the report.
2026-09-04 Publish the Aristo D2 gerbers that were sent to JLCPCB.
    The ordered set matches copper, BOM and CPL already on main; this adds the backside load table from the 31 Aug export.
    [led_panel_4x5.kicad_pcb]
2026-09-04 Show the JLCPCB SMT top view in the Aristo D2 panel README.
    That is the board as ordered, so the picture belongs next to the gerbers rather than only on the tool README.
2026-09-07 Add the FreeCAD Aristo D2 LED holder with 7 mm bosses.
    The taller posts leave room for the thick cable under the panel.
    [panel-holder.FCStd]
2026-09-07 Show the assembled Aristo D2 panel working in its holder.
    The first JLCPCB board is soldered, mounted, and tested — all 109 LEDs run.
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2026-09-07 Require an inline fuse on VIN+ and show the holder.
    An unfused 5 V feed can dump the whole PSU into a short on the panel.
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2026-09-07 Mention the optional cross factor and mark metering as in development.
    The cross-sensitivity correction is an original feature of this project; the sensor/calibration side still needs darkroom testing and must not be read as finished.
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2026-09-13 Add the WS2812B-MINI Aristo D2 panel and printable silk datasheets.
    The v2 board is the 112-LED drop-in head; overlay tables, silk-to-pad gapping, and closed-mask NPTH holes make the back legend and mounting keepouts fab-safe.
    [led_panel_4x5.kicad_pcb, led_panel_4x5.kicad_sch, led_panel_4x5_bom.csv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]
2026-09-13 Mark the WS2812B-MINI panel as work in progress.
    The v1 SK6812 build guide was copied into v2 by mistake; keep gerbers in contrib without inviting anyone to order this revision yet.
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2026-09-14 Keep only the back datasheet on the LED panel and refresh the JLCPCB gerbers.
    [led_panel_4x5.kicad_pcb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]
